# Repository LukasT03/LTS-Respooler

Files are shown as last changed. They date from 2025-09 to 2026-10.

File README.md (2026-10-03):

# LTS Respooler
The LTS Respooler is a compact and slightly over-engineered filament Respooler optimized for Bambu Lab spools. It integrates a filament runout sensor and wireless app-connectivity for ease of use. The LTS Respooler Pro uses a 9g servo motor to precisely position the Filament Guide. You can find all the files related to it here. That includes the raw .txt ESP32 Code, the .bin firmware files and the PCB Gerber files.

## ➡️ Upcoming features and files:
- Official attachment for spools bigger than 1 kg

## 🚀 Getting started
- All the 3D files can be downloaded and printed from [MakerWorld](https://makerworld.com/@lukas.tu)
- Assembly Intructions and the Needed Hardware PDF can also be found there
- Most of the Hardware can be ordered from Bambu Lab's Maker's Supply
- PCBs can be ordered from my [Website](https://lts-design.com) or on [PCBWay](https://www.pcbway.com/project/member/?bmbno=7102E4BB-3522-48)
- Flash the newest firmware version to your ESP32 or LTS Control Board using the [Web Flasher](https://flash.lts-design.com)

## 📋 License
This project is licensed under the MIT license, giving you the freedom to use it however you like. Contributions, modifications, and improvements are very welcome! :)

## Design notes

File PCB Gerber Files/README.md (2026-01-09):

Here you can find the manufacturing data for all the available PCB boards. Feel free to order your own PCBs! They are optimized to be ordered from [JLCPCB](https://jlcpcb.com) but are also available as shared projects on [PCBWay](https://www.pcbway.com/project/member/?bmbno=7102E4BB-3522-48).

Only the Control Board V4 and the Driver Board V1 are still supported.

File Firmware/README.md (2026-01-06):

These are the firmware files for all the board versions. The .bin files are used for the web flasher and OTA updates.

# Changelog:

### 1.2.1
- Changed OTA-Update URL

### 1.2.0
- Added support for upcoming Respooler Pro with precise servo control
- App needs to be uptated to 1.7.0

### 1.1.2
- Added ability to exit Auto-Stop state via long button press
- Fixed issue where speed would decrease after restart

### 1.1.1
- Added support for Control Board V4
- Increased LED brightness

### 1.1.0
- Added option to choose what amount to transfer
- Lowered default fan speed

### 1.0.0
- Added option to pause the Respooler
- Unified current state logic
- Bug fixes

### 0.9.3
- Increased speed and motor strength
- Warning sound in case of Auto-Stop
- Fixed issue where motor strength would decrease after Auto-Stop

### 0.9.2
- Improved stability of Bluetooth connection
  
### 0.9.1
- Fixed bug where High-Speed setting would change after restart
- Bug fixes for Control Board V3
  
### 0.9.0
- First beta version

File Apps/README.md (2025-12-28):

LTS Utility for macOS lets you flash your ESP32 or LTS Control Board with the newest version from GitHub. Using the web flasher at https://flash.lts-design.com is the preferred way if you're on Windows.

The LTS Control app can be downloaded from the [App Store](https://apps.apple.com/app/lts-control/id6742149969). An Android version is in early development. For now, you can use the [Web version](https://control.lts-design.com/).

## 📱 The mobile app has separate repos that are linked below
- 🍏 iOS: https://github.com/LukasT03/LTS-Control-iOS
- 🤖 Android: https://github.com/LukasT03/LTS-Control-Android

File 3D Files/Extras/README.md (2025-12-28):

# 🛠️🧩 This folder contains mods, addons and accesories that are not included with the base files.

## Filament Guide with ECAS04
This alternative for the Filament Guide adds an embedded mount for an ECAS04 bowden pneumatic fitting (compatible with 4 mm OD PTFE tube). This allows the PTFE tube to be mechanically locked to the guide, preventing it from coming loose during operation.

➡️ Available as a print profile on the MakerWorld page.

## Quick-Swap Spool Center
This add-on replaces the "Spool Center" part and allows for quick swapping between different holders for spools from different manufacturers.

➡️ Available [here](https://makerworld.com/models/2045239).

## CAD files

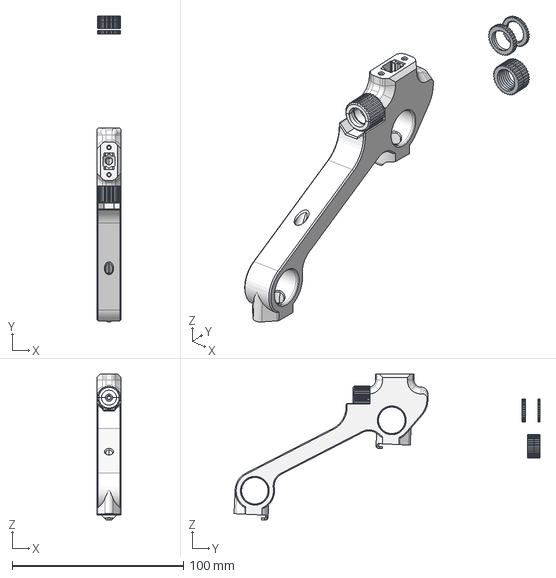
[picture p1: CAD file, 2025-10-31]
3D Files/Extras/Filament Guide (ECAS04 Mount).step
14.0 x 178.8 x 85.3 mm
Frame:1
拓竹P1三通_ECAS04_Bowden鲍登接头.STEP

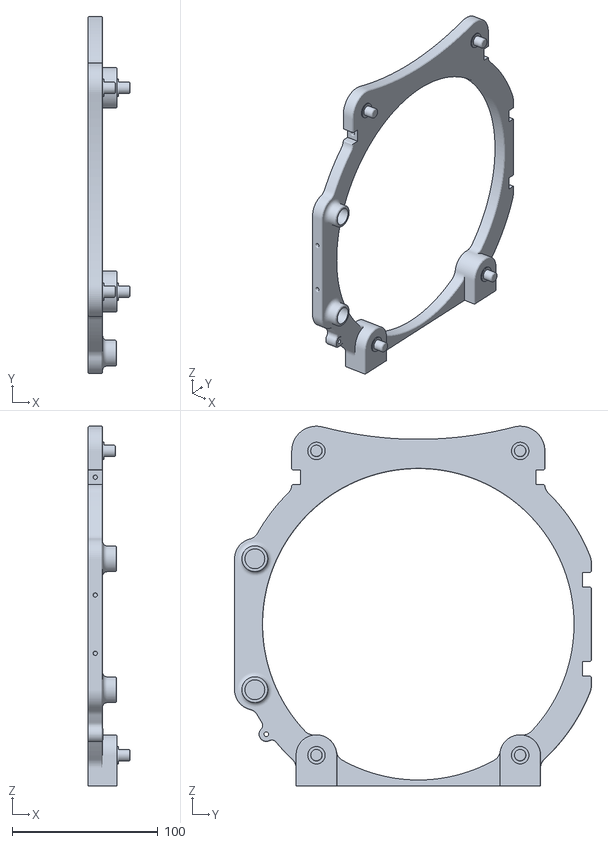
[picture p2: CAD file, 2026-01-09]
3D Files/STLs Pro/Frame L.stl
28.8 x 245.3 x 247.1

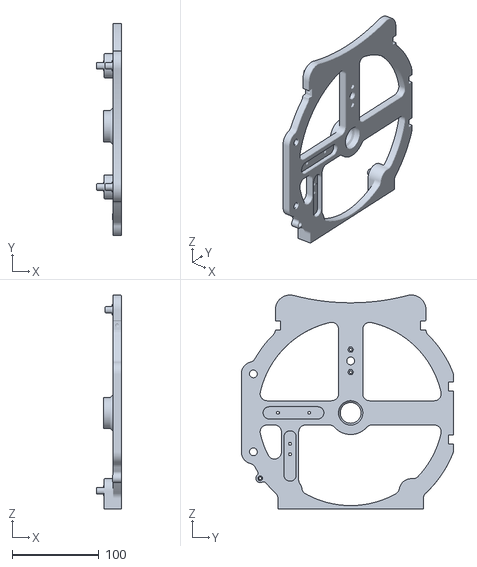
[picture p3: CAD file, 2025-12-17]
3D Files/STLs V4/Frame R.stl
28.8 x 245.3 x 247.1

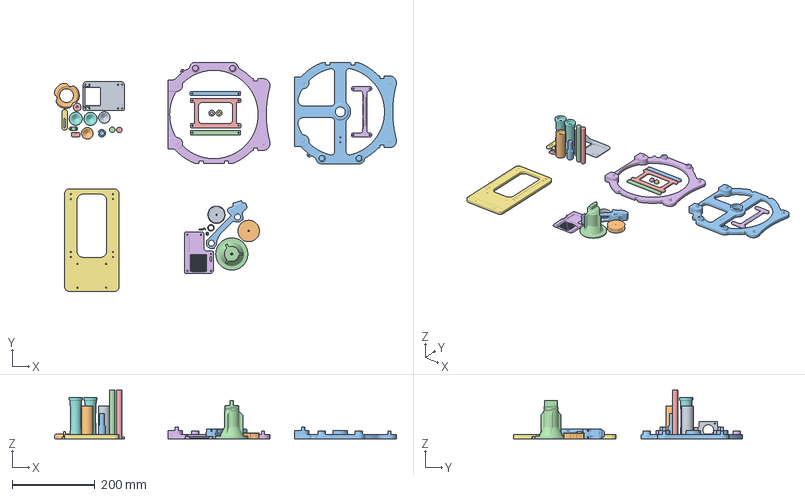
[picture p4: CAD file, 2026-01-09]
Print Profiles/LTS Respooler (Pro).3mf
828.6 x 555.6 x 118.0 mm
bottom Roller.stl x 2
Brace single.stl x 2
Brace double.stl
Frame L.stl
Base.stl
top Roller.stl x 2
washer Spool shaft.stl
Pulley Spool.stl
Frame R.stl
Tension washer 2.stl
Motor Pulley.stl
Tension Pulley 1.stl
Tension Pulley 2.stl
Motor Base.stl
Spool Nut.stl
Filament Guide.stl
Spool Center.stl
Control Panel Button.stl
Electronics Case Lid.stl
Tension Holder 2.stl
Filament Switch Stopper.stl
Gear Filament Guide.stl
Cable Clip.stl
Spool Shaft.stl
Linear Rod.stl x 2
Gear Rack.stl

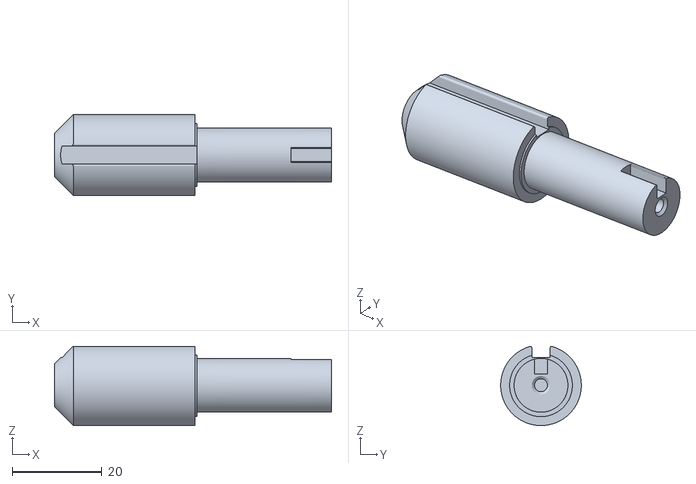
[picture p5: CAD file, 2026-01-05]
3D Files/STLs Pro/Spool Shaft.stl
61.8 x 18.0 x 17.7

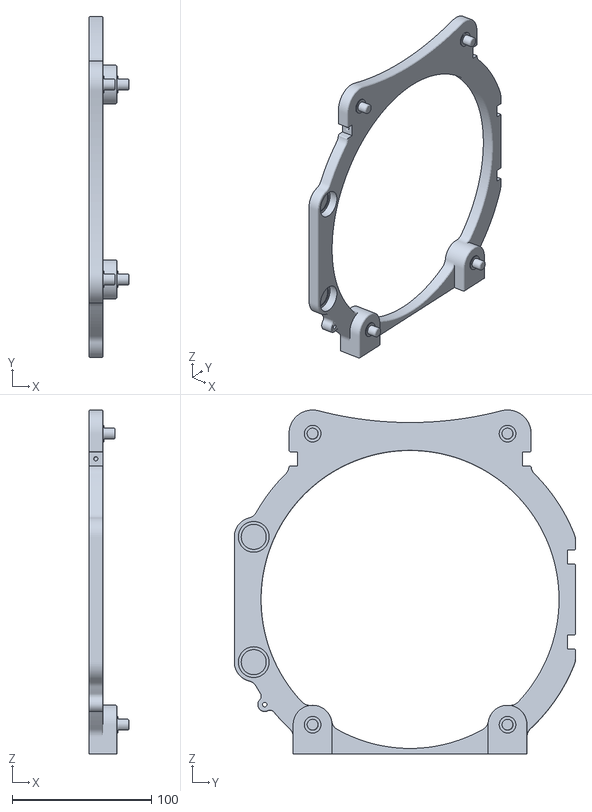
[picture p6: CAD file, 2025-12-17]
3D Files/STLs V4/Frame L.stl
28.8 x 245.3 x 247.1

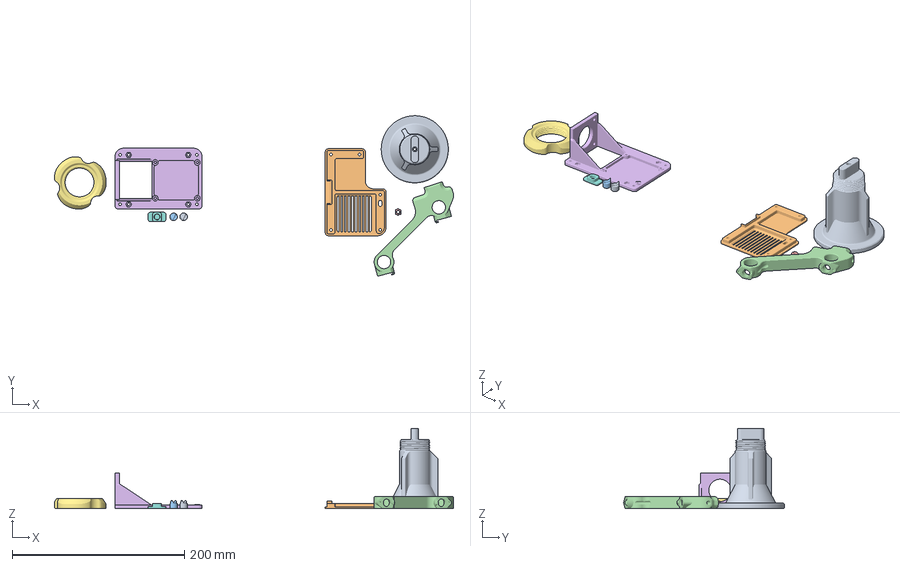
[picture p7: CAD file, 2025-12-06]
Print Profiles/Upgrade (V3 to V4).3mf
463.5 x 186.5 x 93.5 mm
Spool Center.stl
Electronics Case Lid.stl
Filament Guide Pin.stl x 2
Filament Guide.stl
Filament Switch Stopper.stl
Motor Base.stl
Spool Nut.stl
Control Panel Button.stl

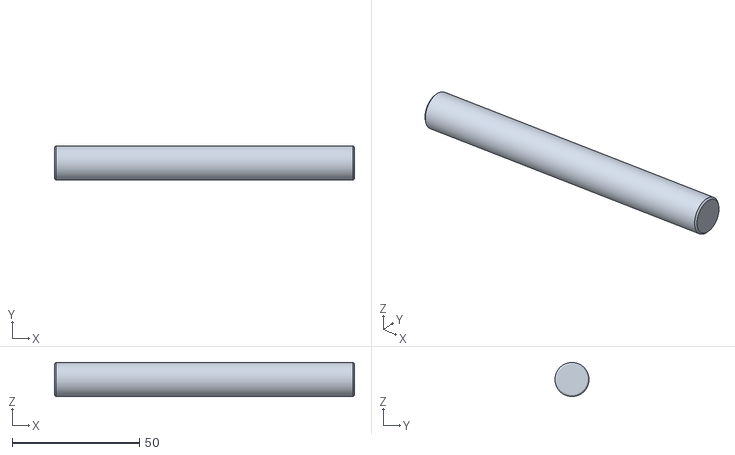
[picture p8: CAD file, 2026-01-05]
3D Files/STLs Pro/Linear Rod.stl
118.0 x 13.4 x 13.4

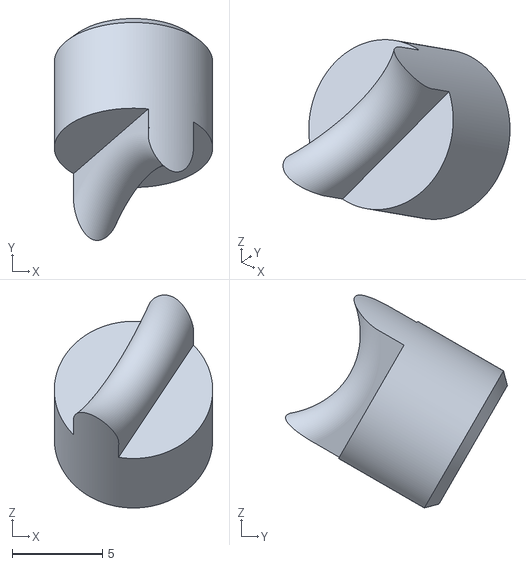
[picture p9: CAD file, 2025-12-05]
3D Files/STLs V4/Filament Guide Pin.stl
8.80 x 12.3 x 11.8

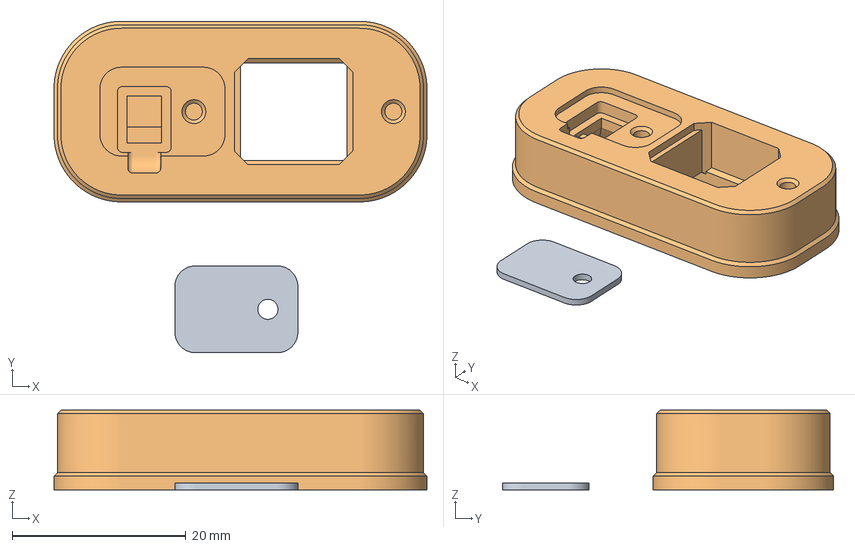
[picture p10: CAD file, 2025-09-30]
Print Profiles/Control Panel (multicolor).3mf
43.0 x 38.2 x 9.20 mm
Control Panel Plate.stl
Control Panel Multi Color 1

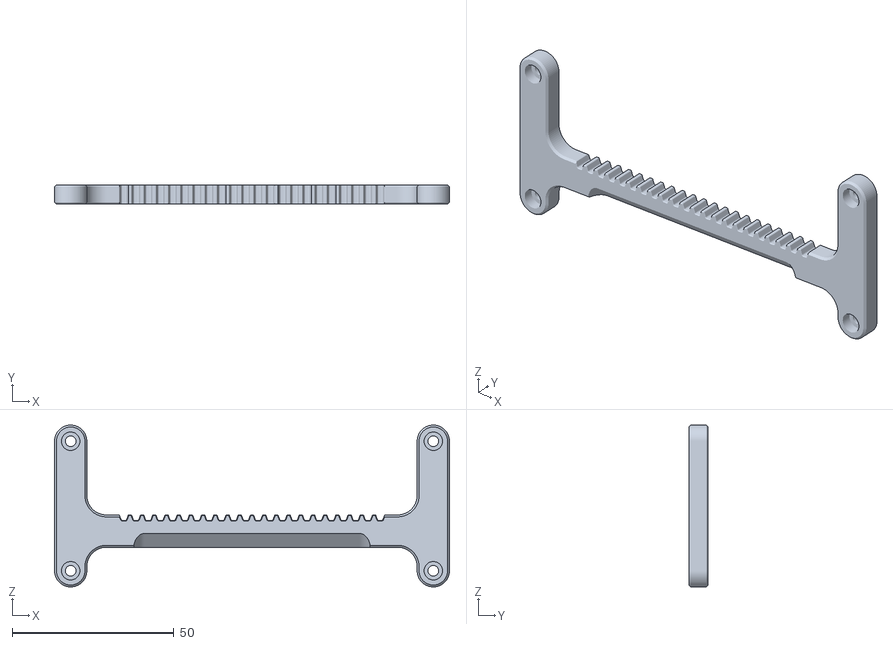
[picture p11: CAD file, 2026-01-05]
3D Files/STLs Pro/Gear Rack.stl
122.0 x 6.00 x 50.0

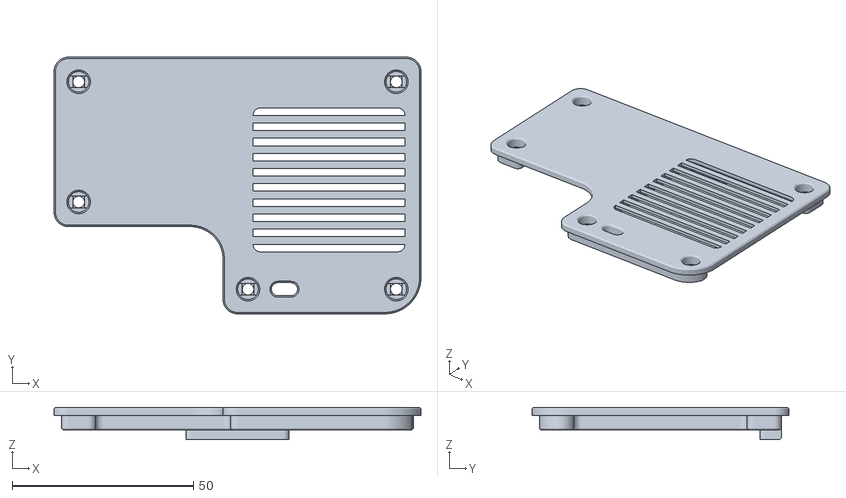
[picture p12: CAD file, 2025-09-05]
3D Files/STLs V4/Electronics Case Lid.stl
101.2 x 70.8 x 8.89

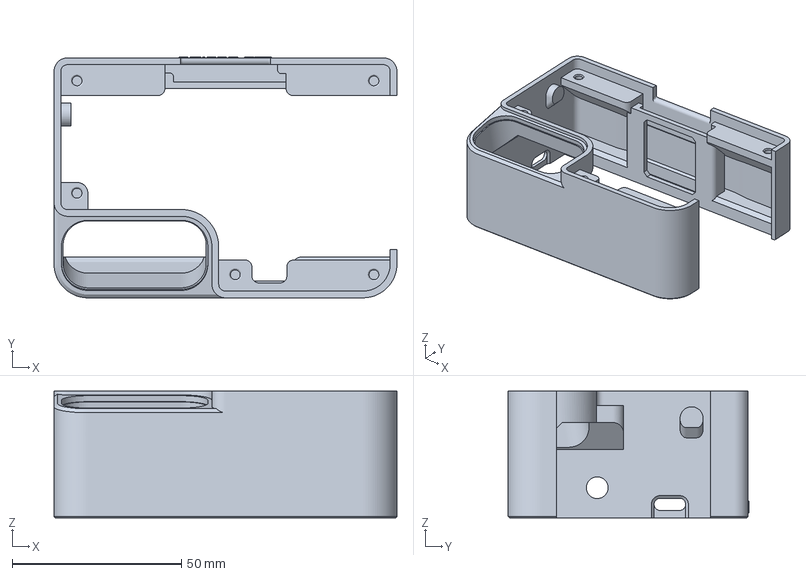
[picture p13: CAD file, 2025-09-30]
Print Profiles/Electronics Case (Control Board V4).3mf
101.2 x 71.0 x 37.4 mm

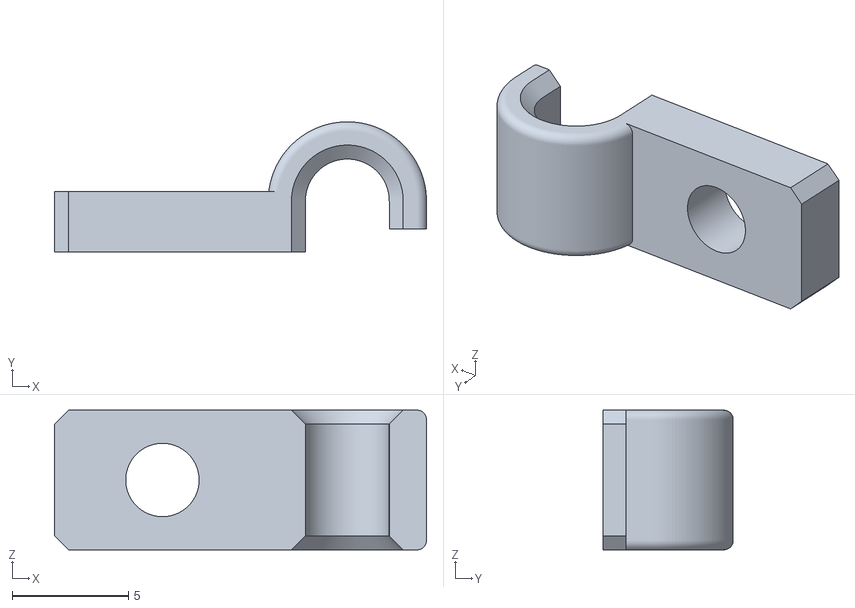
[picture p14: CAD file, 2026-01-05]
3D Files/STLs Pro/Cable Clip.stl
16.0 x 5.60 x 6.00

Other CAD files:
3D Files/STLs V4/Tension Holder 1.stl
Print Profiles/Electronics Case (ESP32).3mf
3D Files/STLs Pro/Electronics Case Lid.stl
Print Profiles/Control Panel (single color).3mf
3D Files/Extras/Filament Guide (ECAS04 Mount).3mf
3D Files/STLs Pro/Bottom Roller.stl
3D Files/STLs Pro/Brace Double.stl
3D Files/STLs Pro/Brace Single.stl
3D Files/STLs Pro/Control Panel Button.stl
3D Files/STLs Pro/Control Panel Multi Color 1.stl
3D Files/STLs Pro/Control Panel Plate.stl
3D Files/STLs Pro/Control Panel Single Color.stl
3D Files/STLs Pro/Electronics Case Control Board.stl
3D Files/STLs Pro/Electronics Case ESP32.stl
3D Files/STLs Pro/Motor Base.stl
3D Files/STLs Pro/Motor Pulley.stl
3D Files/STLs Pro/TPU Foot 1.stl
3D Files/STLs Pro/TPU Foot 2.stl
3D Files/STLs Pro/Tension Holder.stl
3D Files/STLs Pro/Tension Pulley 1.stl
3D Files/STLs Pro/Tension Pulley 2.stl
3D Files/STLs Pro/Tension Washer.stl
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

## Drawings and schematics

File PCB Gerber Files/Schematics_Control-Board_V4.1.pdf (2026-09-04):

IO0 27 IO35 28 IO36 29 IO37 30 IO38 31 IO39 32 IO40 33 IO41 34 IO42 35 RXD0 36 TXD0 37 IO2 38 IO1 39 GND 40

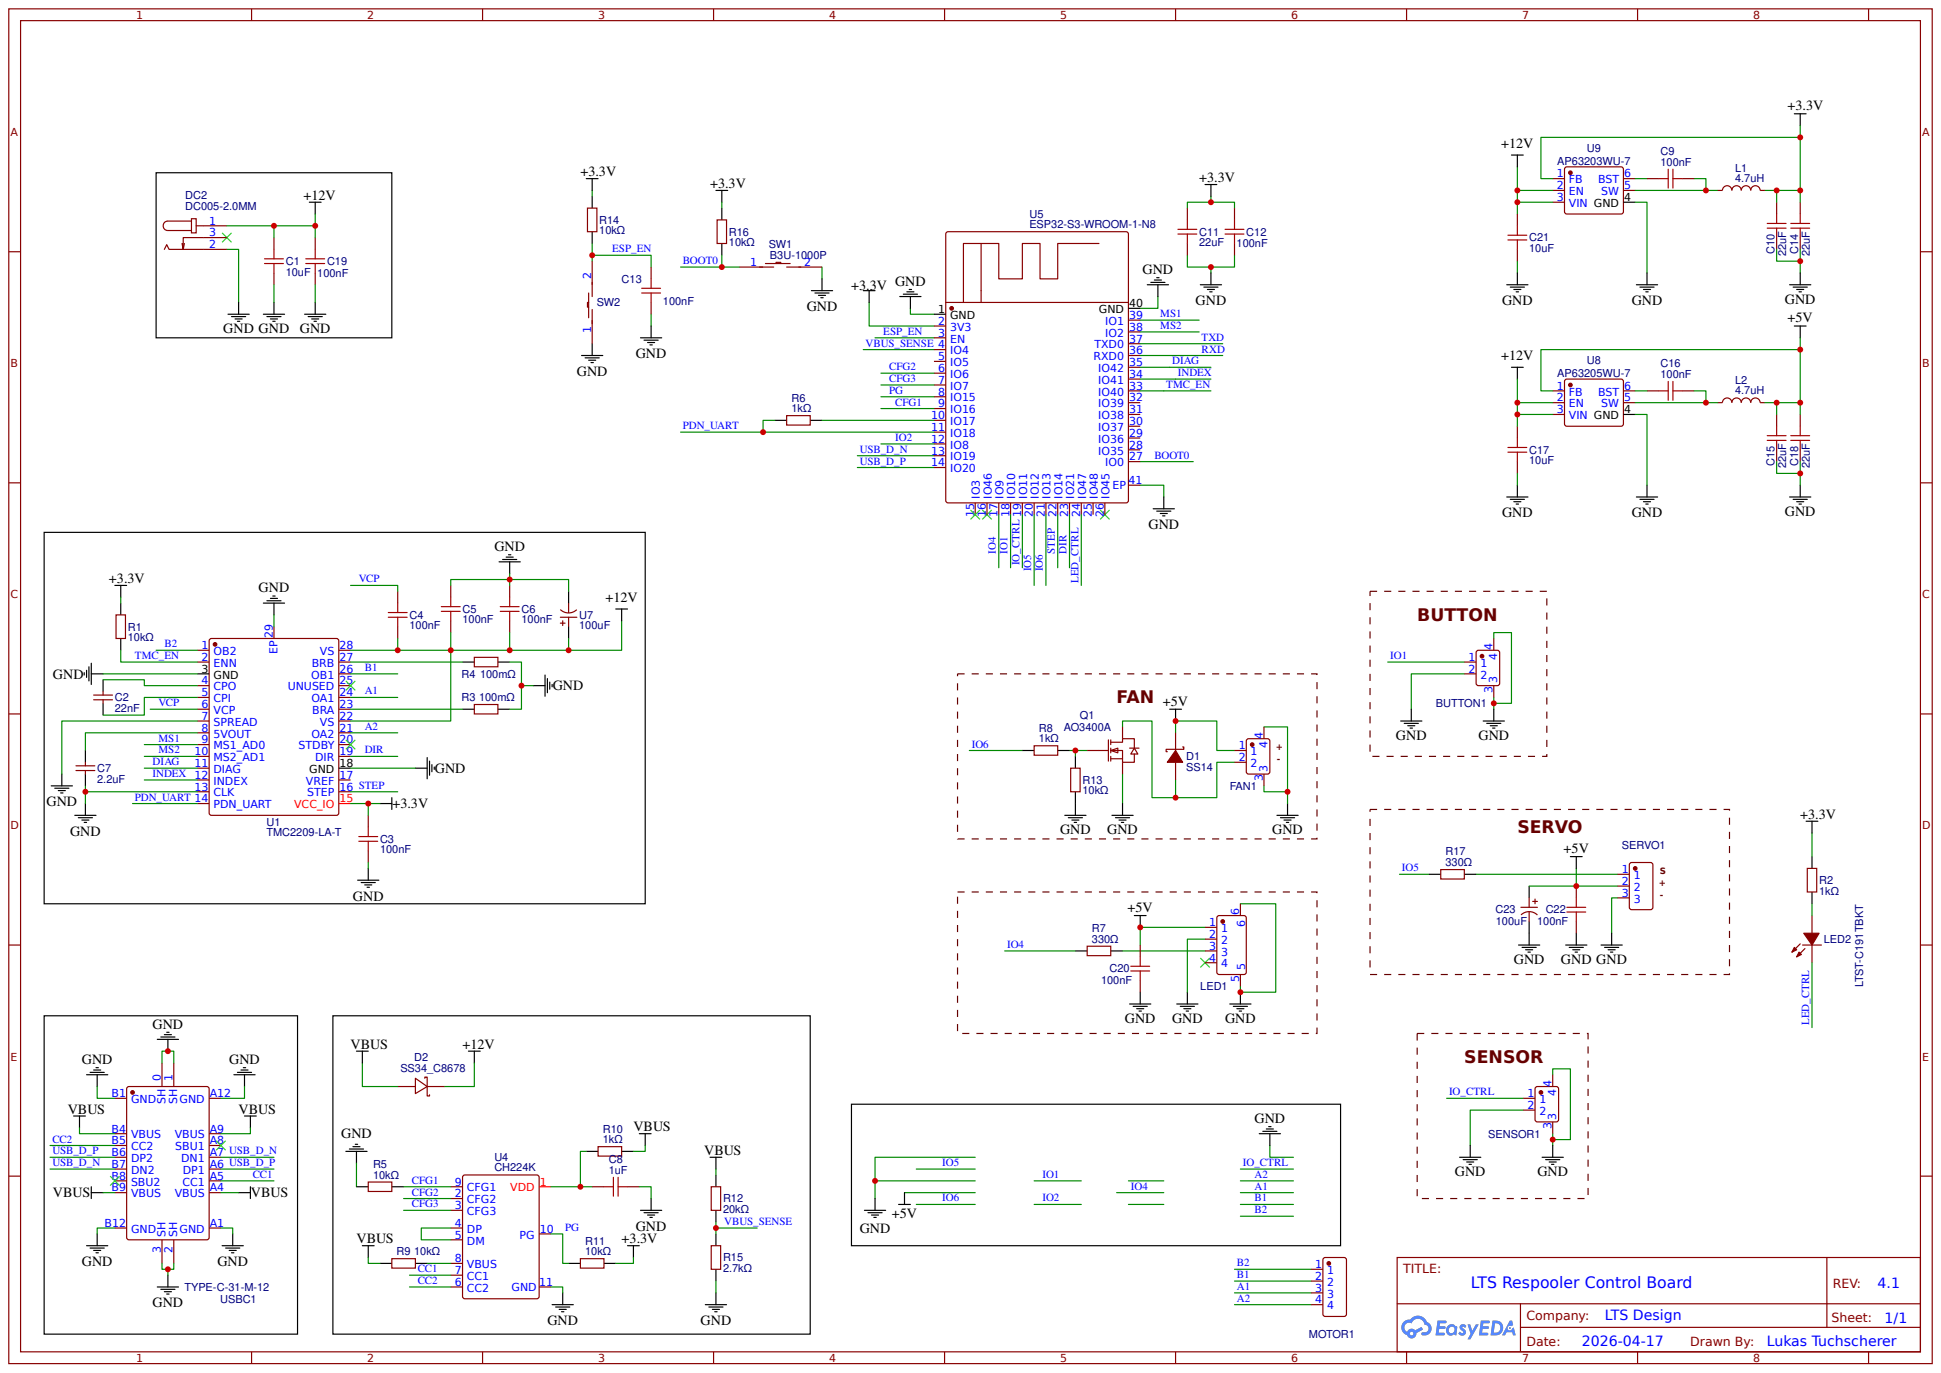
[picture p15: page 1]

SH 1 SH 3 SH 2 GND A1

Drawn By: Lukas Tuchscherer

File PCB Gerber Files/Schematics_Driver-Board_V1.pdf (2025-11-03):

## ESP32

## TMC2209

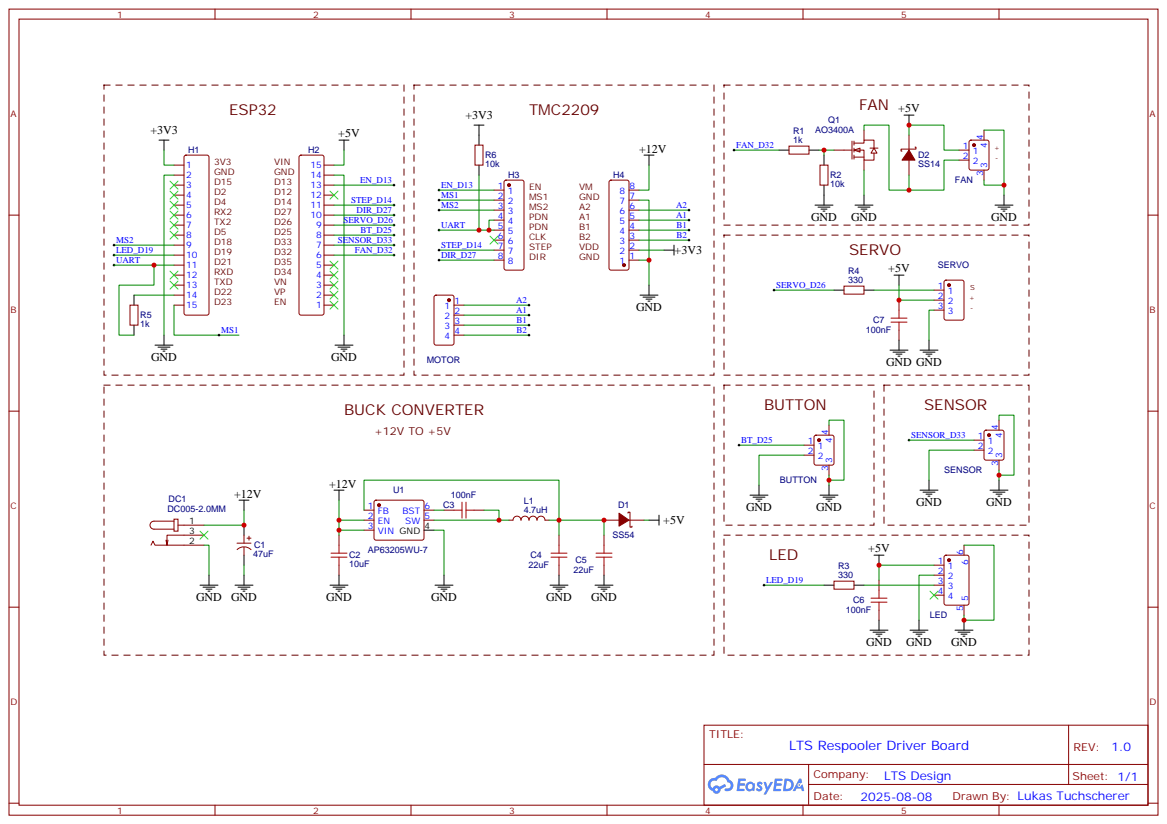
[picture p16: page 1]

Drawn By: Lukas Tuchscherer

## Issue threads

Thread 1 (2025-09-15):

[Firmware] Missing Control Board V4 .bin

62fixolab, 2025-09-15:
I can’t flash the firmware either through the web or the macOS app. Could you upload the Control Board V4 .bin file to the repository?

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

Closed 2025-09-16.

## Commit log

2025-08-21 Create Raw ESP32 Dev Board Code
2025-08-23 Rename Raw ESP32 Dev Board Code to ESP32 Code (.txt)
2025-08-23 Create Arduino Code (.txt)
2025-08-26 Update ESP32 Code (.txt)
2025-09-01 Rename Arduino Code (.txt) to (.txt) Arduino Code
2025-09-01 Create (.txt) Control Board V3 Code
2025-09-01 Create (.txt) ESP32 PCB Code
2025-09-01 Update (.txt) ESP32 PCB Code
2025-10-16 Create (.txt) Control Board V4 Code
2025-10-16 Update (.txt) Control Board V4 Code
2025-10-29 Rename (.txt) ESP32 PCB Code to (.txt) Driver Board Code
2025-10-29 Rename (.txt) Control Board V4 Code to (.txt) Control Board Code
2025-10-29 Rename (.txt) Driver Board Code to (.txt) ESP32 DevKit Code
2025-10-30 Changed Filament Guide geometry
    Adjusted for better PTFE tube fit.
2025-10-30 Changed name from "ESP32 PCB" to "Driver Board"
2025-10-30 Changed name from "ESP32 PCB" to "DriverBoard"
2025-10-31 Add improved Filament Guide with ECAS04 mount to Extras
    This community variant includes an embedded ECAS04 pneumatic fitting mount to prevent PTFE tube slippage during operation. The modification addresses reliability issues where friction alone was insufficient to retain the tube under filament tension.
    Key improvements:
    - Internal cavity for ECAS04 Bowden fitting (4mm PTFE)
    - Mechanical locking prevents tube detachment
    - External geometry unchanged (fully compatible with existing parts)
    - Placed in Extras folder as a community modification
    Files added:
    - 3D Files/Extras/Filament Guide (ECAS04 Mount).step
    [Filament Guide (ECAS04 Mount).step]
2025-10-31 Add Bambu Lab print profile for ECAS04 variant
    Includes optimized 3MF print profile for the Filament Guide with ECAS04 mount.
    This allows users to directly import the configuration into Bambu Studio/Bambu Lab printers.
    - 3D Files/Extras/Filament Guide (ECAS04 Mount).3mf
    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
    [Filament Guide (ECAS04 Mount).3mf]
2025-10-31 Add STEP model for upcoming Pro version with servo
2025-11-03 Added PCB schematics for Driver Board
2025-12-05 Add PCB ordering information to README
2025-12-05 Fix typo in PCB ordering instructions
2025-12-05 Add PCBWay as an ordering option for PCBs
    Updated README to include PCBWay as an ordering option.
2025-12-05 Update README with PCBWay ordering note
    Added a note about PCBWay ordering not being tested.
2025-12-05 Update Filament Guide (not new)
    Not a new version, just forgot to update it a while ago. Now same version that's been on MakerWorld for some time.
2025-12-05 Updated Filament Guide Pin for better reliability
    Now 0.2 mm longer which improves reliability and smoothness of the guide movement.
    [Filament Guide Pin.stl]
2025-12-07 Update to 1.1
    - faster flashing speed
    - remove option for Control Board V3
2025-12-14 Rename (.txt) ESP32 DevKit Code to (.txt) Driver Board Code
2025-12-16 Add belt to 3D model
2025-12-17 Fix mounting hole being too small on Frame R
2025-12-17 Fix mounting holes being too small
    [Frame L.stl, Frame R.stl]
2025-12-19 Add supports to Frame R
2026-01-03 Update to 1.2
    - Add automatic board version detection
    - Add support for flashing config for V4/Pro version
2026-01-04 Update to 1.2.2
    - Add icon to "Check for Updates..." menu button
2026-01-09 Fix mounting hole being too short
    [Frame L.stl]
2026-09-04 Added PCB schematics for Control Board
2026-10-22 Add Arduino source for Control Board and Driver Board firmware (1.2.1)
2026-10-22 Firmware 1.3.0
    - Disable TMC2209 analog current scaling (VREF is tied to GND), so the
    configured motor current is actually applied
    - Use SpreadCycle in high-speed mode for more torque
    - Report VBUS_MV and PG in status
    - Fix remaining-time drift
2026-11-05 Firmware 1.3.1
    - Driver Board: Ship the 1.2.1 build as 1.3.1, since 1.3.0 crashes on the
    ESP32 due to an LEDC change in ESP-IDF 5.5.5
    - Control Board: Same build as 1.3.0
2026-11-05 Update Driver Board hardware to V1.1
2026-11-09 Firmware 1.3.2
    - Only write LEDC duty when it changes, since ESP-IDF 5.5.5 can hang the
    ESP32 on frequent updates
    - Reset LEDC at startup so a stuck channel can't survive a reboot
    - Build with arduino-esp32 3.3.1 (ESP-IDF 5.5.1) again
2026-11-09 Prepare firmware 1.3.3
    - Filament sensor sensitivity (FIL_T: 100/200/400 ms), the loss window
    scales with speed (#10)
    - Power loss recovery (RES): while the motor runs, progress and servo
    position are saved every 2 s and restored paused after a restart
    - Reference time is calibrated at 85 % speed, existing 80 % values are
    converted and rounded to 5 s
    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
2026-11-13 Rebuild Control Board 1.3.3 with USB CDC
    The arduino-cli build lacked USBMode=hwcdc,CDCOnBoot=cdc, so Serial used
    UART0 instead of USB and flashers could not set the variant.
